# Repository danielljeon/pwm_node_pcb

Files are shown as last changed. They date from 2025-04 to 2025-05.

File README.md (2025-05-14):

# pwm_node_pcb



PCB for CAN-controlled PWM controller.

- Firmware: [`pwm_node`](https://github.com/danielljeon/pwm_node).

---

<details markdown="1">
  <summary>Table of Contents</summary>

<!-- TOC -->
* [pwm_node_pcb](#pwm_node_pcb)
  * [1 Overview](#1-overview)
  * [2 Board Specifications](#2-board-specifications)
    * [2.1 Connectors](#21-connectors)
    * [2.2 Switches & Jumpers](#22-switches--jumpers)
  * [3 Release Notes](#3-release-notes)
    * [3.1 v0.1.0-alpha](#31-v010-alpha)
<!-- TOC -->

</details>

---

## 1 Overview

| Top | Bottom |
|:---:|:---:|
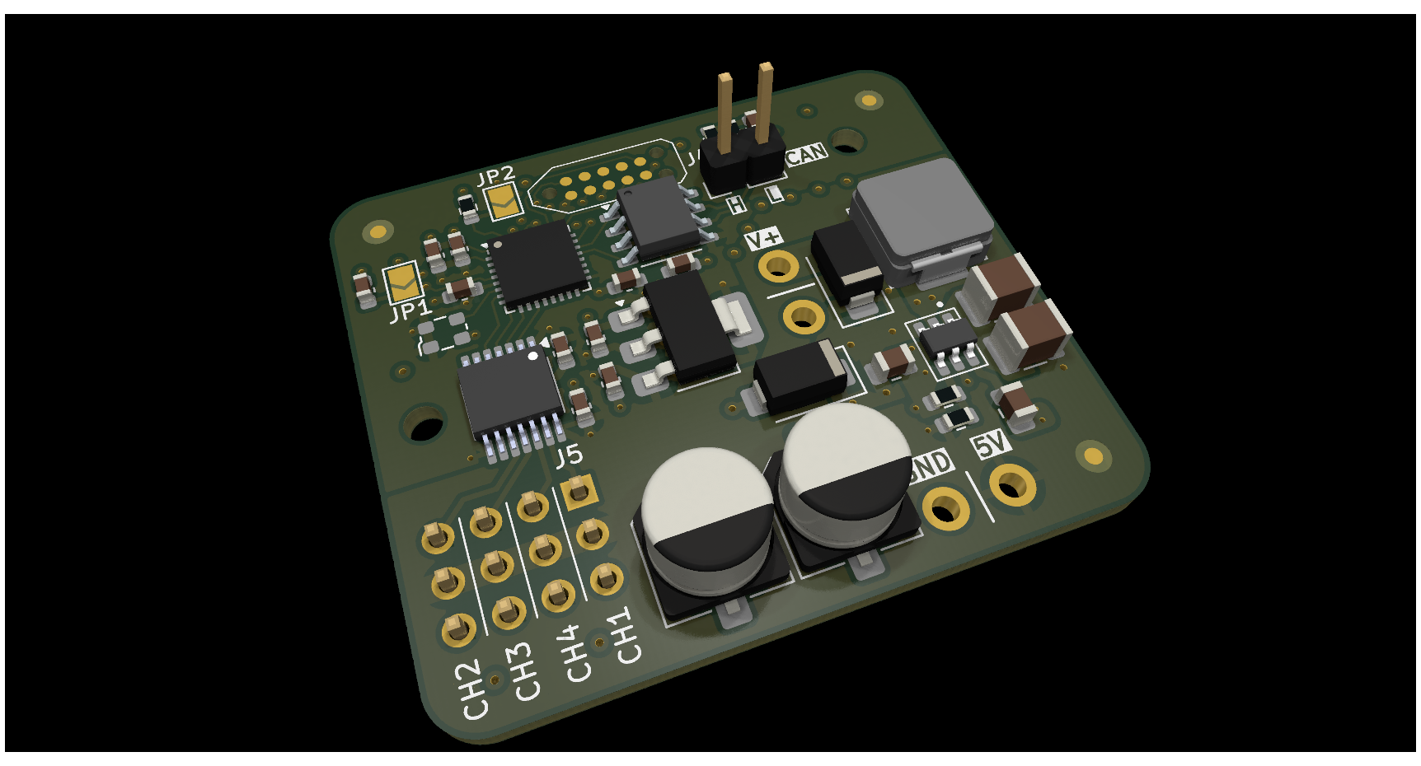
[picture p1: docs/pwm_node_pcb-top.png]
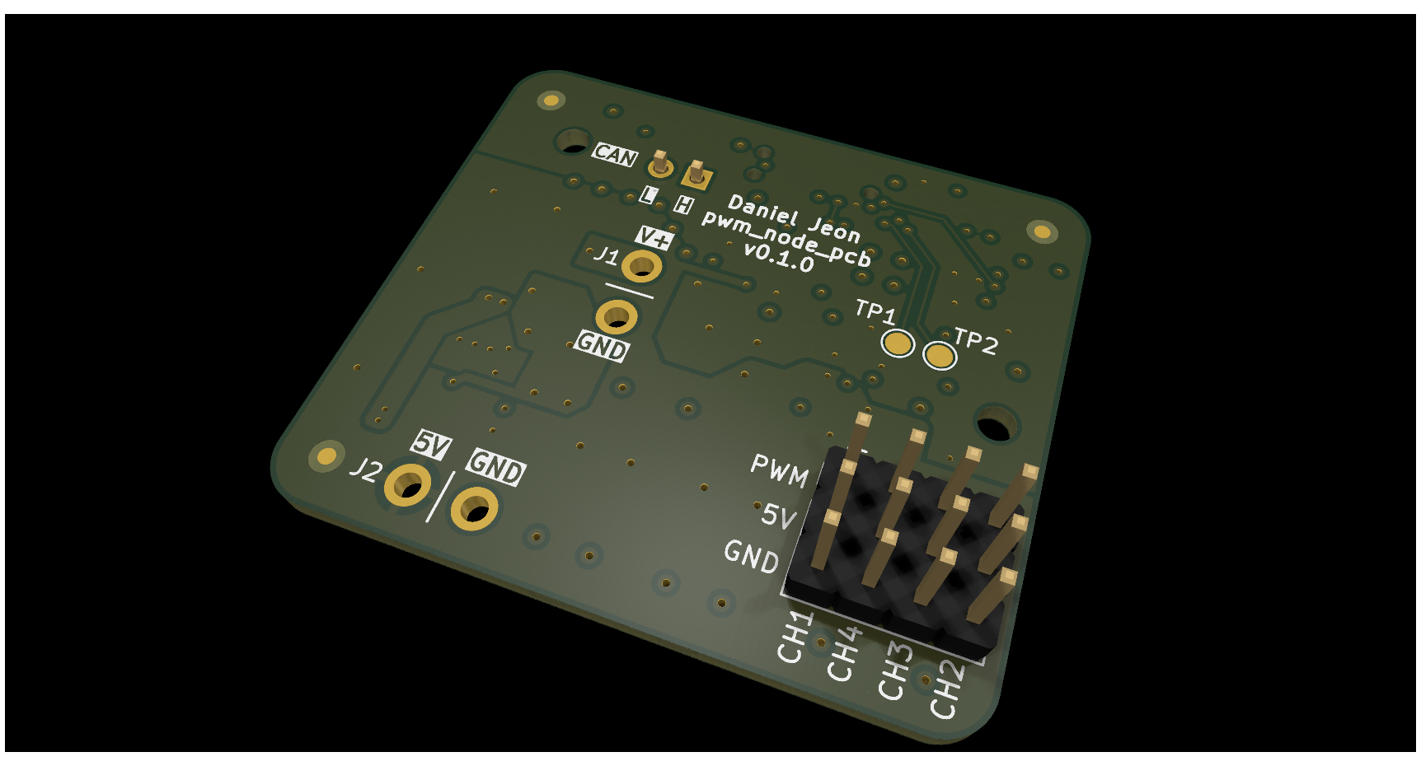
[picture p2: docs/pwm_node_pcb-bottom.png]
|  |  |

---

## 2 Board Specifications

### 2.1 Connectors

Connectors fixed by hardware (PCB traces or the connector itself).

| Connector | Ref | Description |
|---|:---:|---|
| Battery (input) | J1  | Battery supply input |
| 5 V Breakout (output) | J3  | 5 V output from buck converter |
| Tag-Connect TC2050 | J3  | Programming/debug connector |
| V Load (input) | J4  | Load supply input |
| 4x Load connectors | J5  | Pin row 1: PWM, Pin row 2: V Load, Pin row 3: Ground |
| CAN1 | J6  | Pin 1: CAN1 High, Pin 2: CAN1 Low |
| MCU NRESET jumper | JP1 | Short to reset |

### 2.2 Switches & Jumpers

User controllable hardware and/or firmware driven inputs.

| Switch/Jumper | Ref | Description |
|---|:---:|---|
| BOOT0 jumper  | JP2 | Open for run flash memory (pull-down on open) |
| Test pad 1 | TP1 | 1.5 mm diameter test pad, chosen for `PB6` (UART TX) |
| Test pad 2 | TP2 | 1.5 mm diameter test pad, chosen for `PB7` (UART RX) |

---

## 3 Release Notes

### 3.1 v0.1.0-alpha

- Pre-release 4-layer board variant.
    - Short-term pre-release board bring-up/testing release.
- Order date: 2025/04/29.

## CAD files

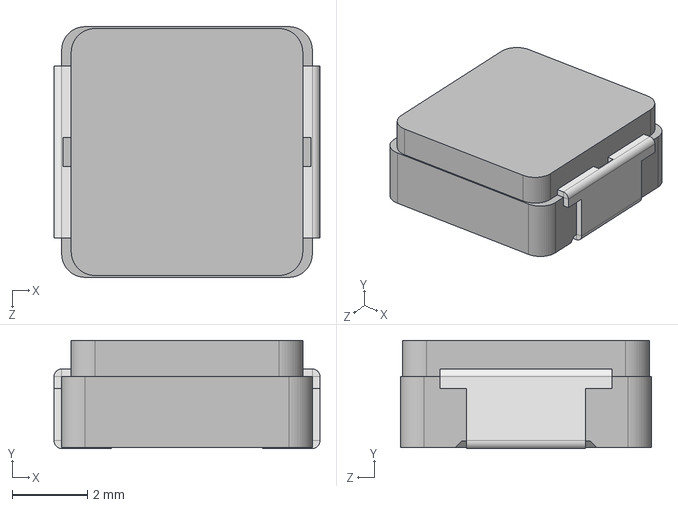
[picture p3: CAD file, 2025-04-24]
component_local/model_3d/IHLP2525CZ.step
7.08 x 2.88 x 6.67 mm

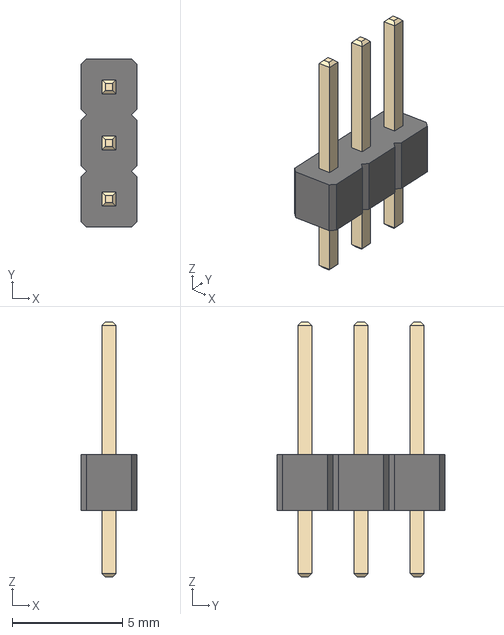
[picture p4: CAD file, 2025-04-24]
component_local/model_3d/PinHeader_1x03_P2.54mm_Vertical.step
2.54 x 7.62 x 11.5 mm

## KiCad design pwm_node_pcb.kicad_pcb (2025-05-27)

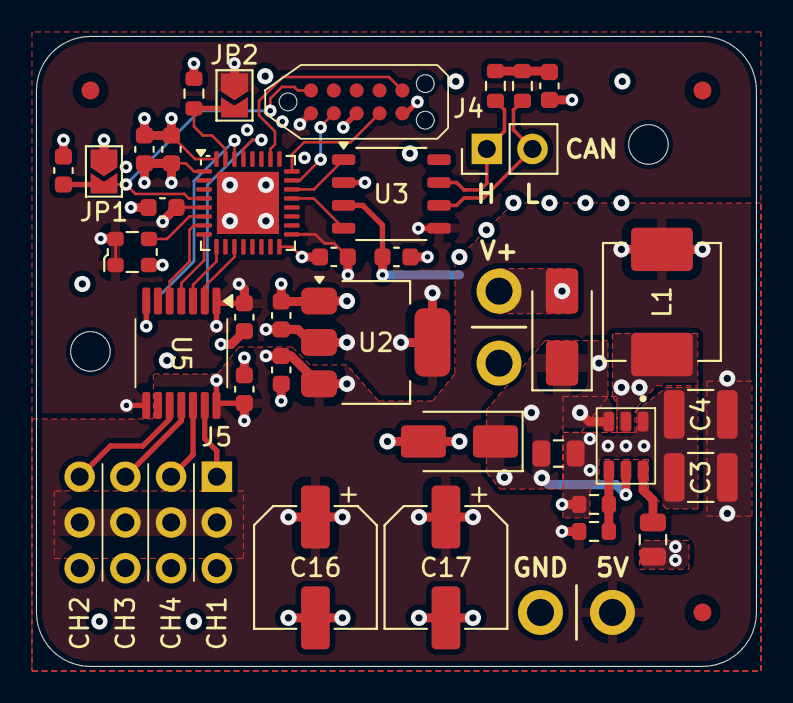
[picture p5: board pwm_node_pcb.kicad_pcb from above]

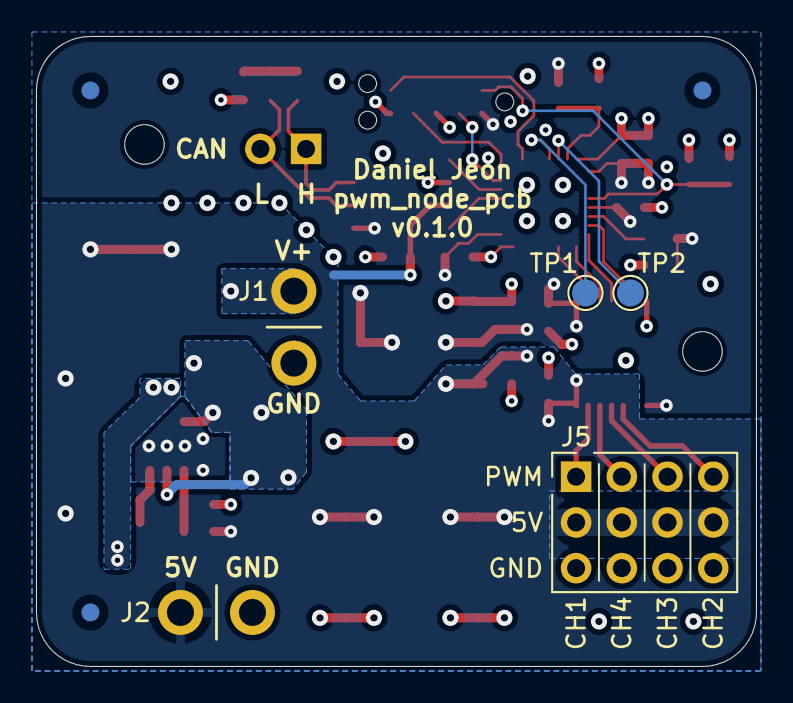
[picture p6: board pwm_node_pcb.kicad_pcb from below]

Board: 4 copper layers, 40.0 x 35.0 mm, 48 parts (8 on the bottom side), 29 nets.

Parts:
C1: 100n; C_0805_2012Metric
C2: 2u2; C_0805_2012Metric
C3, C4: 22u; C_1210_3225Metric
C5, C7, C8, C9, C10, C12, C14, C15: 100n; C_0603_1608Metric
C6: 10u; C_0603_1608Metric
C11: 4u7; C_0603_1608Metric
C13: 4n7; C_0603_1608Metric
C16, C17: 220u; CP_Elec_6.3x5.2
D1: SK36A-LTP; D_SMA
D2: SMAJ15A-13-F; D_SMA
FM1, FM2, FM3, FM4, FM5, FM6: 1mm; Fiducial_1mm_Mask2mm
H1, H2: M2; MountingHole_2.2mm_M2
J1: Battery; battery
J2: 5V Breakout; battery
J3: TC2050-IDC-NL; tag_connect_tc2050-idc-nl
J4: CAN1; PinHeader_1x02_P2.54mm_Vertical
J5: 3x4_2-54mm_breakout
JP1, JP2: Open; SolderJumper-2_P1.3mm_Open_TrianglePad1.0x1.5mm
L1: 6u8; vishay_ihlp-2525cz
R1: 100k; R_0603_1608Metric
R2: 13k7; R_0603_1608Metric
R3, R4: 60R; R_0603_1608Metric
R5: 10k; R_0603_1608Metric
TP1: UART_TX; TestPoint_Pad_D1.5mm
TP2: UART_RX; TestPoint_Pad_D1.5mm
U1: LMR51430; lmr51430
U2: LD1117S33CTR; SOT-223-3_TabPin2
U3: TJA1051T/3; sot96-1_soic-8
U4: STM32L432KCU; QFN-32-1EP_5x5mm_P0.5mm_EP3.45x3.45mm
U5: TXB0104QPWRQ1; txb0104qpwrq1
Y1: ECS-2520MV-080-BN; Oscillator_SMD_ECS_2520MV-xxx-xx-4Pin_2.5x2.0mm

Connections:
+3V3: C6.1, C8.1, C9.1, C10.1, C11.1, C14.1, J3.1 (VCC), JP2.1 (A), U2.2 (VO), U3.5 (V_{IO}), U4.1 (VDD), U4.5 (VDDA), U4.17 (VDD), U5.1 (V_{CCA}), U5.8 (OE), Y1.1 (Tri-State), Y1.4 (VDD)
+5V: C3.2, C4.2, C5.1, C7.1, C15.1, C16.1, C17.1, J2.1, J5.2, J5.5, J5.8, J5.11, L1.2, R1.2, U2.3 (VI), U3.3 (V_{CC}), U5.14 (V_{CCB})
+VSUPPLY: C2.1, D1.1 (K), D2.1 (A1), U1.3 (VIN), U1.5 (EN)
/BOOT0: JP2.2 (B), R5.1, U4.31 (BOOT0)
/BUCK_SW: C1.2, L1.1, U1.2 (SW)
/CAN1+: J4.1, R4.1, U3.7 (CANH)
/CAN1-: J4.2, R3.1, U3.6 (CANL)
/CAN1_RX: U3.4 (RXD), U4.21 (PA11)
/CAN1_TX: U3.1 (TXD), U4.22 (PA12)
/NRST: C12.2, J3.10 (~RESET), JP1.2 (B), U4.4 (NRST)
/PWM1_{5V}: J5.1, U5.13 (B1)
/PWM2_{5V}: J5.10, U5.10 (B4)
/PWM3_{5V}: J5.7, U5.11 (B3)
/PWM4_{5V}: J5.4, U5.12 (B2)
/SWCLK: J3.4 (SWCLK/TCK), U4.24 (PA14)
/SWDIO: J3.2 (SWDIO/TMS), U4.23 (PA13)
/SWO: J3.6 (SWO/TDO), U4.26 (PB3)
/TIM1_CH1: U4.11 (PA5), U5.2 (A1)
/TIM1_CH2: U4.7 (PA1), U5.5 (A4)
/TIM1_CH3: U4.8 (PA2), U5.4 (A3)
/TIM1_CH4: U4.9 (PA3), U5.3 (A2)
/USART1_RX: TP2.1, U4.30 (PB7)
/USART1_TX: TP1.1, U4.29 (PB6)
GND: C2.2, C3.1, C4.1, C5.2, C6.2, C7.2, C8.2, C9.2, C10.2, C11.2, C12.1, C13.2, C14.2, C15.2, C16.2, C17.2, D2.2 (A2), J1.2, J2.2, J3.3 (GND), J3.5 (GND/VPROG), J5.3, J5.6, J5.9, J5.12, JP1.1 (A), R2.2, R5.2, U1.1 (GND), U2.1 (GND), U3.2 (GND), U4.16 (VSS), U4.32 (VSS), U4.33 (VSS), U5.7 (GND), Y1.2 (GND)
unnamed: C13.1, R3.2, R4.2
unnamed: D1.2 (A), J1.1
unnamed: C1.1, U1.6 (CB)
unnamed: R1.1, R2.1, U1.4 (FB)
unnamed: U4.6 (PA0), Y1.3 (OUT)

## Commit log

2025-04-24 Add WIP passing ERC DRC
    [PinHeader_1x03_P2.54mm_Vertical.step, pwm_node_pcb.kicad_pcb, pwm_node_pcb.kicad_sch]
2025-04-24 Add re-layout WIP changes
    [pwm_node_pcb.kicad_pcb, pwm_node_pcb.kicad_sch]
2025-04-24 Cleanup layout and routing
    [pwm_node_pcb.kicad_pcb]
2025-04-24 Fix component libraries
    [IHLP2525CZ.step, PinHeader_1x03_P2.54mm_Vertical.step]
2025-04-24 Revamp schematic and nuke PCB
    [pwm_node_pcb.kicad_pcb, pwm_node_pcb.kicad_sch]
2025-04-24 Initial component placement
    [pwm_node_pcb.kicad_pcb, pwm_node_pcb.kicad_sch]
2025-04-24 Split load supply and rough placement
    [pwm_node_pcb.kicad_pcb, pwm_node_pcb.kicad_sch]
2025-04-24 Pass ERC and DRC, initial v0.1.0-alpha
    [pwm_node_pcb.kicad_pcb, pwm_node_pcb.kicad_sch]
2025-04-24 Fix old broken footprints
    [pwm_node_pcb.kicad_pcb]
2025-04-24 Update KiBot workflow for KiCad 9
2025-04-24 Add version silkscreen and update pictures
    [pwm_node_pcb.kicad_pcb]
2025-04-28 Add minor decoupling caps, board cleanup
    [pwm_node_pcb.kicad_pcb, pwm_node_pcb.kicad_sch]
2025-04-28 Trace cleanup
    [pwm_node_pcb.kicad_pcb]
2025-04-28 Add TVS and schottky diodes
    [pwm_node_pcb.kicad_pcb, pwm_node_pcb.kicad_sch]
2025-04-29 Add GND plane stitching vias
    [pwm_node_pcb.kicad_pcb]
2025-04-29 Add testpads/UART breakout
    [pwm_node_pcb.kicad_pcb, pwm_node_pcb.kicad_sch]
2025-04-29 Fix silkscreen and load caps to 220uF
    [pwm_node_pcb.kicad_pcb, pwm_node_pcb.kicad_sch]
2025-05-08 Fix flipped UART breakout (TP) nets
    [pwm_node_pcb.kicad_pcb, pwm_node_pcb.kicad_sch]
2025-05-08 Fix level shifter circuit
    [pwm_node_pcb.kicad_pcb, pwm_node_pcb.kicad_sch]
2025-05-09 Update sch and pcb sheet info
    [pwm_node_pcb.kicad_pcb, pwm_node_pcb.kicad_sch]
2025-05-10 Fix load cap fp and remove dedicated supply
    [pwm_node_pcb.kicad_pcb, pwm_node_pcb.kicad_sch]
2025-05-12 Minimize use of inpad vias
    [pwm_node_pcb.kicad_pcb]
2025-05-14 Update README.md for PCB-firmware references
2025-05-14 Add TVS and schottky diode info
    [pwm_node_pcb.kicad_pcb, pwm_node_pcb.kicad_sch]
2025-05-27 Fix missing outer layer non-functional pads (vias)
    [pwm_node_pcb.kicad_pcb]
2025-06-03 Update config.kibot.yaml for KiCad/Bot 9

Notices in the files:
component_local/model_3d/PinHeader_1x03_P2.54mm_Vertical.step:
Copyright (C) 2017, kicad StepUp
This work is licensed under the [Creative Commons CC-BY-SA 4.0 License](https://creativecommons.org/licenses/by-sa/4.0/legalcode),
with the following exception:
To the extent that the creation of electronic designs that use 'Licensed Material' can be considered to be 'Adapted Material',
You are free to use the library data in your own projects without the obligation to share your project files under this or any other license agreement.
